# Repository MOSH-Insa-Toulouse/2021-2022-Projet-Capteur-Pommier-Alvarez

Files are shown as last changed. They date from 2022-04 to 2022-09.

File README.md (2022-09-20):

# 2021-2022-Projet-Capteur-Pommier-Alvarez
 
## Description Générale

Dans le cadre de l’unité de formation « Du capteur et banc de test » de l’année scolaire 2021-2022 en quatrième année de Génie Physique à l’INSA Toulouse, nous devions réaliser une jauge de contrainte à base de graphite.

Afin de mener ce projet à bien tout en respectant l’esprit autour de ce capteur (Low tech, low cost et transportable), nous avons utilisé une carte Arduino Uno, un PCB, et différents composants détaillés par la suite.

## Table des matières
* [Livrables](#livrables)
* [Composants](#comp)
* [LTSpice](#spice)
* [PCB Shield](#pcb)
* [Application](#apk)
* [Arduino](#ard)
* [Banc de test](#banc)
* [Datasheet](#data)
* [Améliorations](#ameliorations)

<div id='livrables'/>

## Livrables

Les livrables à l’issu de ce projet sont:
* Un rapport sur le circuit analogique à l'aide du logiciel LTSpice
* Un PCB Shield
* Un code Arduino permettant de collecter et transférer les données du capteur soit
sur un oled soit à un module bluetooth connecté à un Android.
* Une application APK
* Un banc de test
* Une datasheet

<div id='comp'/>

## Composants

Les composants pour la réalisation du circuit analogique sont les suivants :
* Arduino Uno
* LTC1050
* Module Bluetooth HC05
* OLED 128x64
* Encodeur rotatif GT055
* R4 : Capteur papier
* Résistances: 100kOhms (x2), 1kOhms(x2), 10kOhms
* Capacités: 100nF(x3), 1uF

<div id='spice'/>

## LTSpice

Le rapport sur le circuit analogique se trouve dans le dossier [LTSpice](https://github.com/MOSH-Insa-Toulouse/2021-2022-Projet-Capteur-Pommier-Alvarez/tree/main/LTSPICE)

<div id='pcb'/>

## PCB Shield

La première étape dans la création du PCB a été la création du Schematic sur le logiciel KiCAD. Nous devions créer chacun des composants et déterminer à quels pin de l'Arduino étaient connectés chacun ds pins des composants.

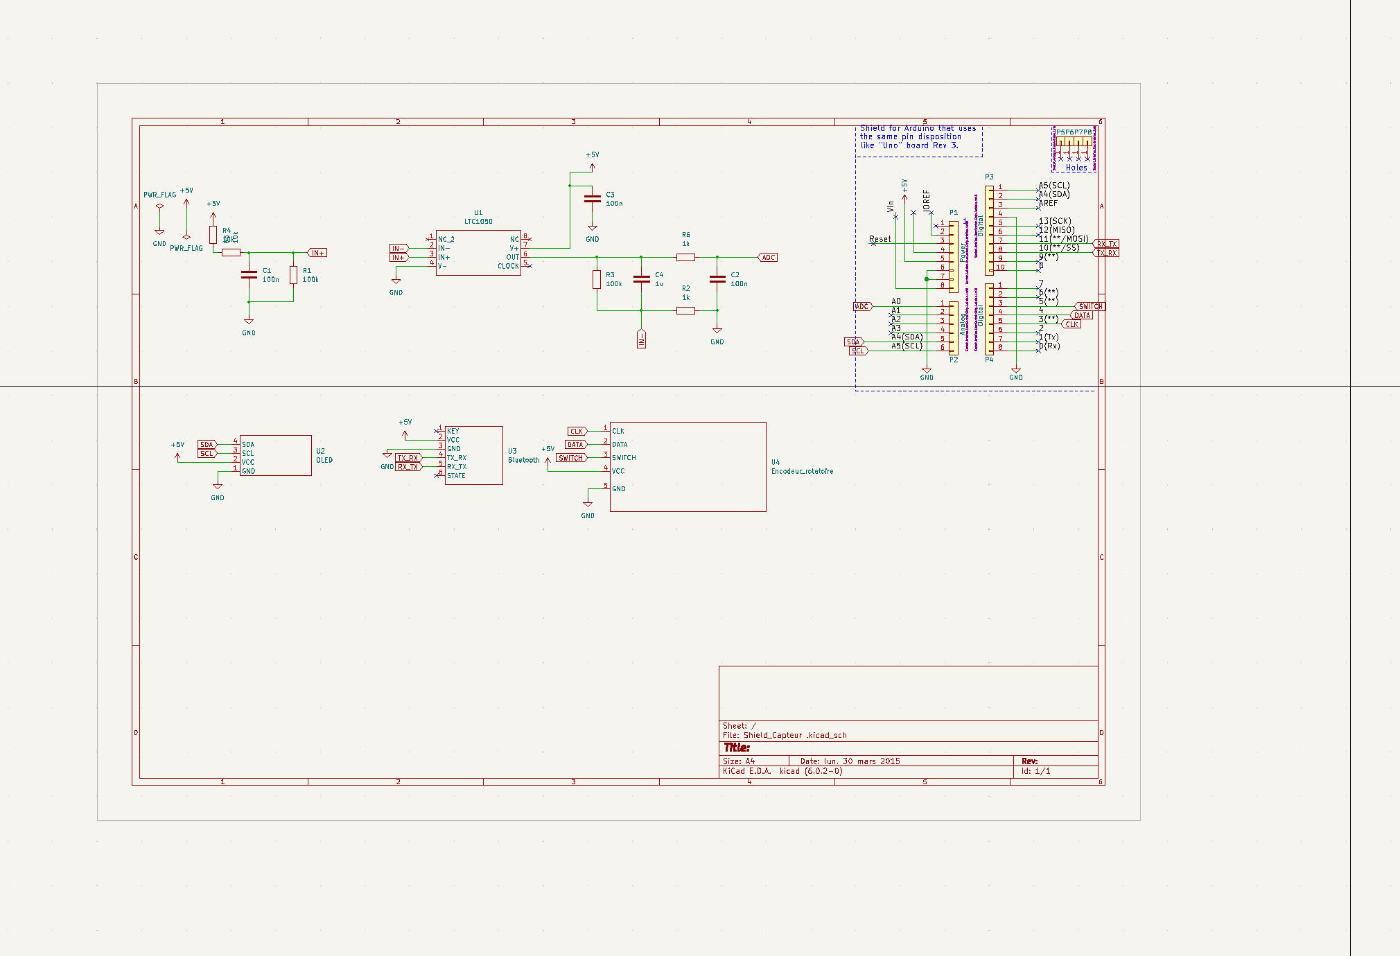
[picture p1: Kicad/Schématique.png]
Shematic


L'étape suivante a été le placement des composants sur le PCB et la connexion entre chaque pin et finalement, la représentation 3D des composants pour s'assurer qu'aucun ne se chevauchaient.

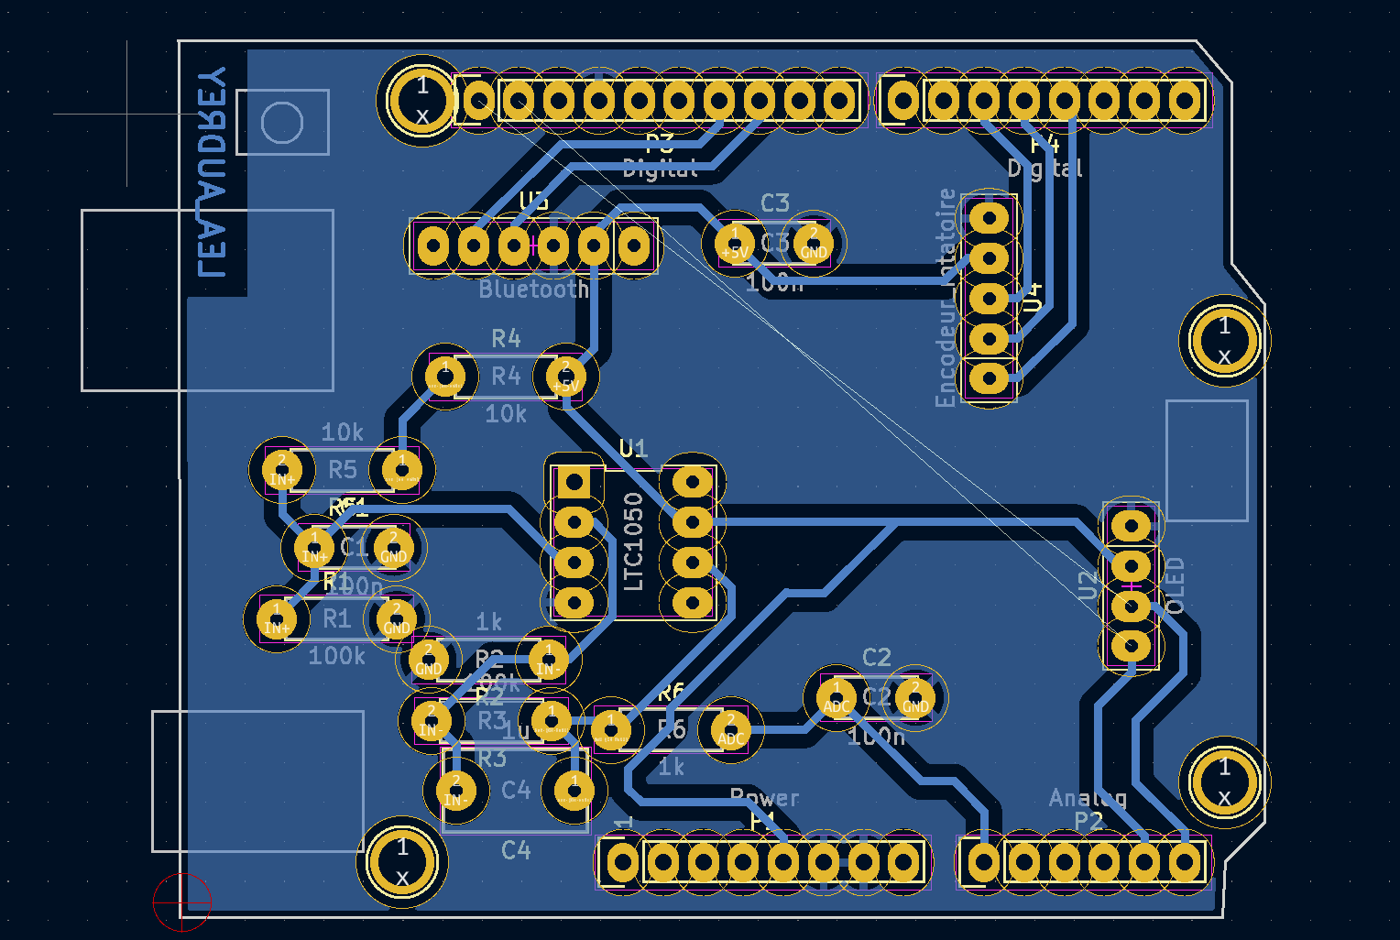
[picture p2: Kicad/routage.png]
routage


Après l'étape de réalisation du PCB avec le logiciel KiCAD est venue l'étape de réalisation physique de celui-ci. C'est avec l'aide de Madame Crouzet que cela a été possible.

Enfin, le PCB a été percé avec des trous de 1mm de diamètre pour les pins de
l'Arduino et 0,8mm de diamètre pour les autres.

Les détails du PCB et du Schematic se trouvent dans le dossier [KiCAD](https://github.com/MOSH-Insa-Toulouse/2021-2022-Projet-Capteur-Pommier-Alvarez/tree/main/Kicad) 

<div id='apk'/>

## Application

Les informations envoyées par le module bluetooth sont récupérées sur une application Android faite grâce au site [MIT App Inventor](https://appinventor.mit.edu/).

Notre application se compose de trois écrans différents. Le premier est une page de garde qui permet d'accéder aux deux autres écrans, soit un écran d'informations générales sur le fonctionnement du capteur soit un écran qui permet la connexion bluetooth et la visualisation des données reçues.
Sur ce dernier la valeur de la résistance est affichée dans une zone texte et tracée au et à mesure sur un graphique.

Voici l'ecran avec le graphique:

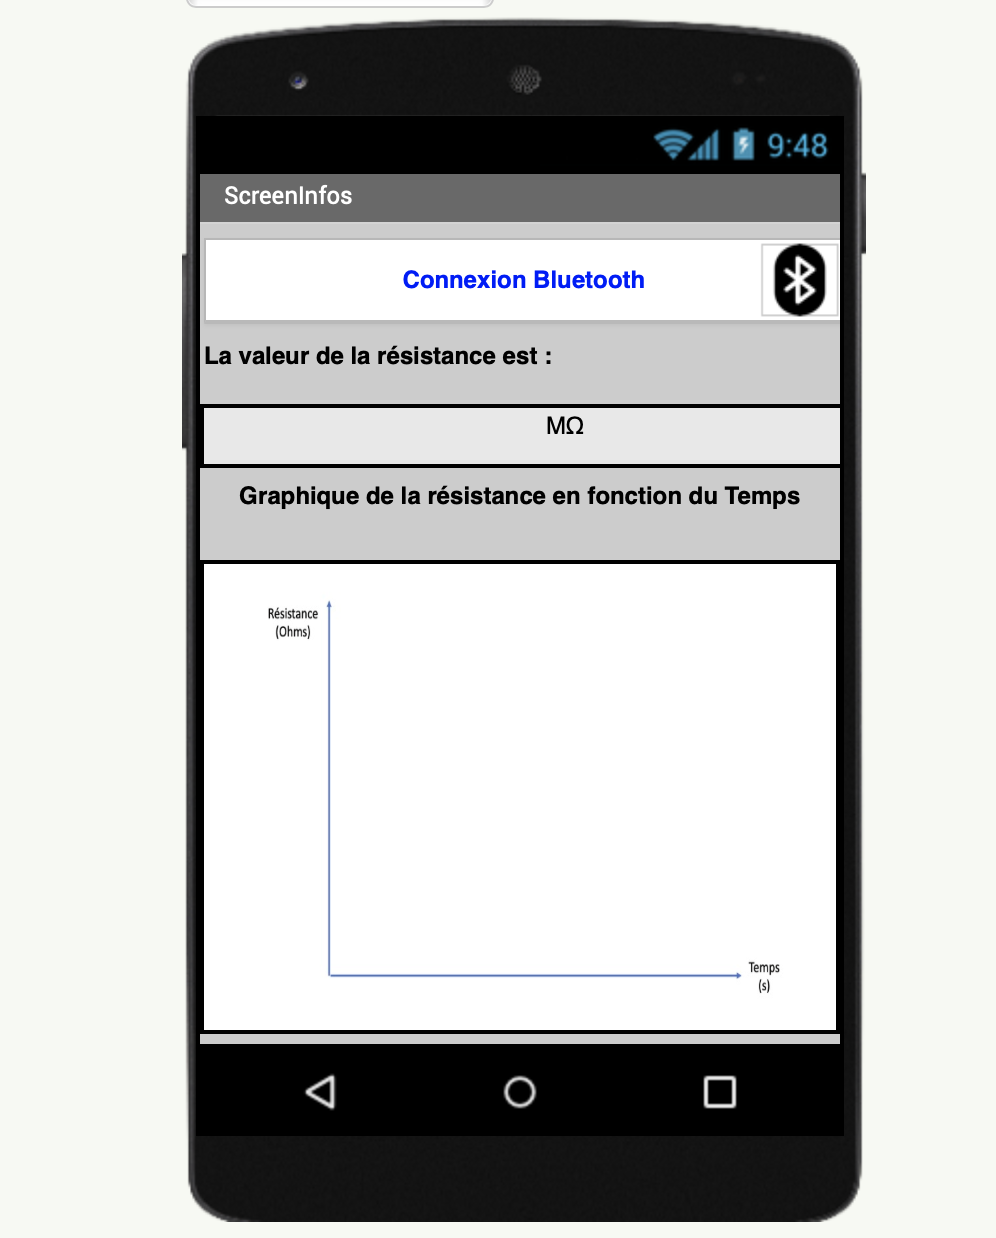
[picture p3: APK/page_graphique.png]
graph


Les photos et le code de l'application se trouvent dans le dossier [APK](https://github.com/MOSH-Insa-Toulouse/2021-2022-Projet-Capteur-Pommier-Alvarez/tree/main/APK)

<div id='ard'/>

## Code Arduino

Afin que tout cela soit possible et fonctionnel nous devions écrire un code Arduino. Celui-ci permet de récupérer les valeurs de la résistances, se connecter au module bluetooth avec un téléphone et les envoyer par la suite. Il permet également de visualiser ces valeur sur un écran OLED constitué de trois menus différents pilotés par l'encodeur rotatif. Ces trois menus sont une page de présentation, une page d'informations et une page avec les valeurs.
Un autre code fut nécéssaire pour pouvoir gérer notre banc de test, celui-ci sera expliqué dans la partie suivante.

Les informations relatives au code se trouvent dans le dossier [Arduino](https://github.com/MOSH-Insa-Toulouse/2021-2022-Projet-Capteur-Pommier-Alvarez/tree/main/Arduino).

<div id='banc'/>

## Banc de test

Afin de pouvoir rédiger notre datasheet mais également de pouvoir connaître la répétabilité de la mesure avec un seul capteur nous avions besoin d'un banc de test. Celui-ci fut réalisé en collaboration avec le groupe de Louis-Maxence Hotton et Thalia Lamy.
Notre banc de test est composé d'un servo-moteur et de pièces recyclées (papier et carton recyclés). Un code Arduino permet de piloter celui-ci et de faire une rotation de 0° à 90°. Afin d'avoir les valeurs en compression et dilatation nous avons retourné le capteur.

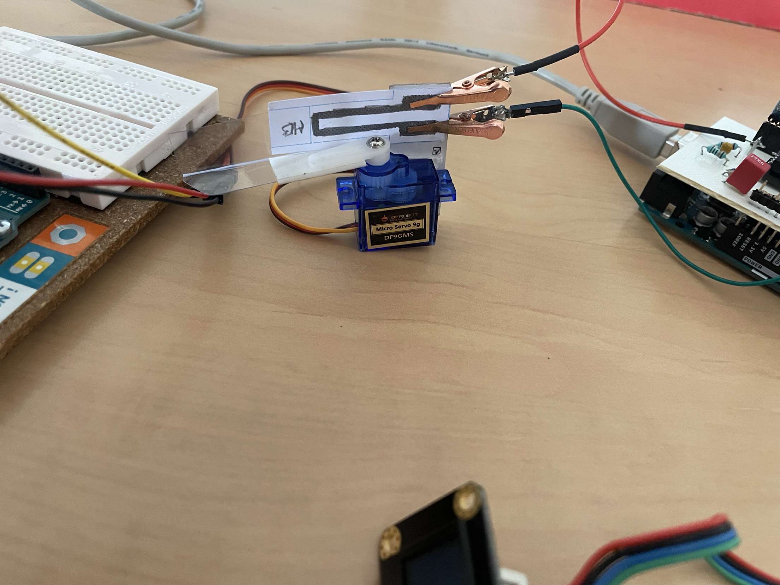
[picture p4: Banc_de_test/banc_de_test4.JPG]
banc de test


Les photos du banc de test sont dans le dossier [banc de test](https://github.com/MOSH-Insa-Toulouse/2021-2022-Projet-Capteur-Pommier-Alvarez/tree/main/Banc_de_test) et le code associé dans le dossier Arduino

<div id='data'/>

## Datasheet

Les données de la datasheet ont été mesurées à l'aide du banc de test décrit ci- dessus. Nous avons fait les mesures avec des crayons HB et 2B. Pour les mesures nous avons fait cinq séries en compression, effectué la moyenne de ces séries et répété l'opération avec la dilatation pour chacun des crayons.
Nous avons testé avec un crayon 6B mais notre programme nous annonçait un overload.

Nous avons estimé la répétabilité de l'expérience à 10 mesures par capteur (papier) soit 5 en compression suivies de 5 en dilatation car après cela les valeurs nous semblaient moins cohérentes avec les premières séries.

La datasheet se trouve dans le dossier [datasheet](https://github.com/MOSH-Insa-Toulouse/2021-2022-Projet-Capteur-Pommier-Alvarez/blob/main/Datasheet%20jauge%20de%20contrainte%20graphite.pdf).

<div id='ameliorations'/>

## Améliorations

L'utilisation du banc de test a nécessité deux cartes Arduino Uno. Il aurait fallu intégrer le servo moteur sur le KiCAD pour pouvoir le mettre sur le PCB et ainsi le faire fonctionner avec une seule carte et un seul programme.

Comme améliorations pour les valeurs de la datasheet, peut être faudrait-il utiliser plusieurs capteurs avec le même crayon (par exemple HB), faire les 10 séries de mesures et faire la moyenne sur toutes les séries des différents capteurs.

On peut également penser pour l'application à l'affichage d'un message pour signaler que la connexion bluetooth s'est effectuée.

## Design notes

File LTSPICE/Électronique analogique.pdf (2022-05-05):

Électronique analogique : simulation sous LTSPICE.

Description générale :

L'objectif de cette partie est de comprendre comment on obtient la résistance de notre capteur à partir du circuit électronique suivant. En effet, l'ordre de grandeur des résistances mesurées sera de 1 Gohms à 500 Kohms. Ce qui signifie que le capteur possède un courant très faible (environ 100 nA). Le montage électrique doit donc comporter un amplificateur opérationnel AOP, dans notre cas il s'agit du LTC1500C (voir datasheet dans le dossier LTSPICE). En effet, le microcontrôleur Arduino Uno ne peut pas mesurer directement de très faible courant C'est pourquoi l’amplificateur opérationnel permettra de convertir ce courant en une tension mesurable par le Arduino Uno.

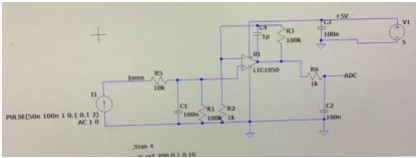
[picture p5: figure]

Schéma électrique du montage

Ce premier schéma permet de réaliser nos mesures pour le capteur graphite. Cependant, si on choisit de prendre le courant du capteur directement en entrée d’amplificateur opérationnel, il est nécessaire que la résistance d'entrée soit très grande pour amplifier le signal et que la tension d'alimentation soit négative. De plus, sous LTSpice, il est possible de voir le courant d'entrée de l’amplificateur opérationnel qui est de 125 pA. En effet, le courant d'entrée doit être très petit devant le courant de notre capteur (100 nA) afin que le courant du capteur traverse la résistance R1 et pas l'entrée de l'amplificateur opérationnel. De plus, si le courant de polarisation et trop grand, cela impactera la tension de sortie et donc faussera le calcul de la résistance.

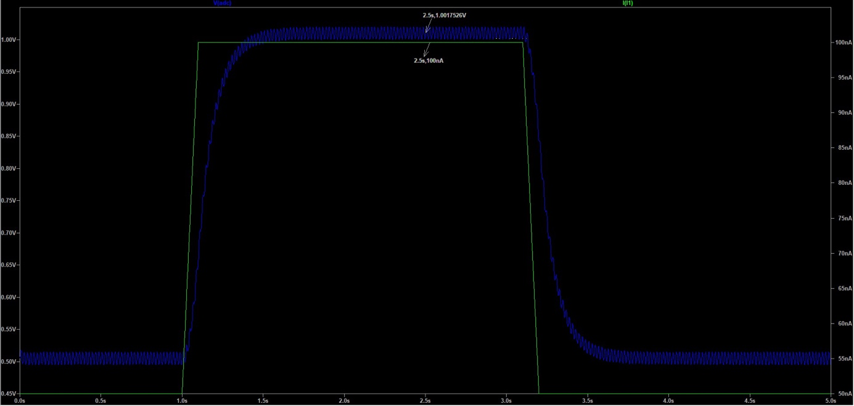
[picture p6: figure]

Mise en évidence : 100nA et 1V

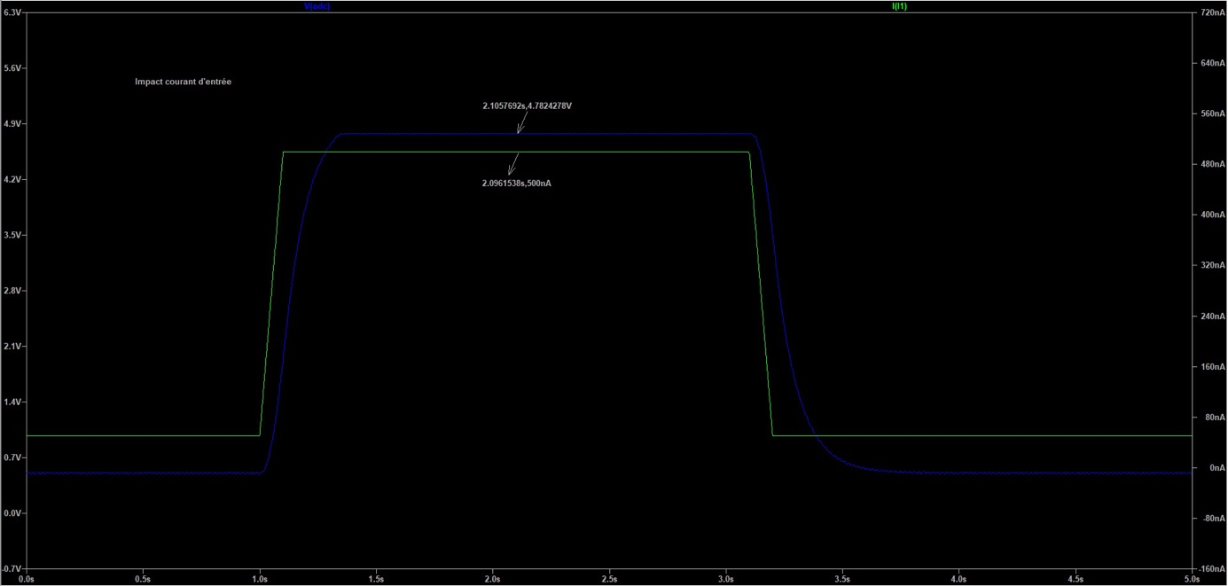
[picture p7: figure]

Mise en évidence : 500nA et 5V

Il est facile de remarquer que si la tension du capteur est de 100 nA, la tension de sortie ADC peut aller jusqu'à un Volt. En revanche, si la tension du capteur est de 500 nA, la tension de sortie ADC peut aller jusqu'à 5 volts. Afin de minimiser ce problème, il faudrait que la résistance R2 soit un potentiel digital afin de réguler celle-ci et de permettre de ne jamais saturer.

Il est intéressant de savoir si elle exerce une influence sur la tension de sortie mesurée. En effet l'offset est une erreur constante aux entrées de l’amplificateur différentiel dû à un état non compensé sur l'étage d'entrée de l'amplificateur. On veut que l’offset soit négligeable devant la tension mesurée. Or d'après la datasheet du LTC1500C, il y a un offset de 05 microvolts (valeurs typiques) et le gain maximal de l’AOP et de 160 dB. Ce qui correspond à un offset de sortie d'environ 50 volts. Cependant la tension mesurée sur R1 est de 10 millivolts, ce qui correspond à une tension en sortie de l’AOP d'environ un giga Volt (10 mV * Gain (le calcul n’est pas exactement cela car il faut prendre en compte les différents filtres…)). On a donc un offset bien plus faible que la tension mesurée, il est donc acceptable d'avoir cet offset.

Les filtres intégrés :

Considérons à présent les différents filtres mis sur ce circuit. En effet, on peut identifier trois filtres passe-bas sur ce circuit analogique.

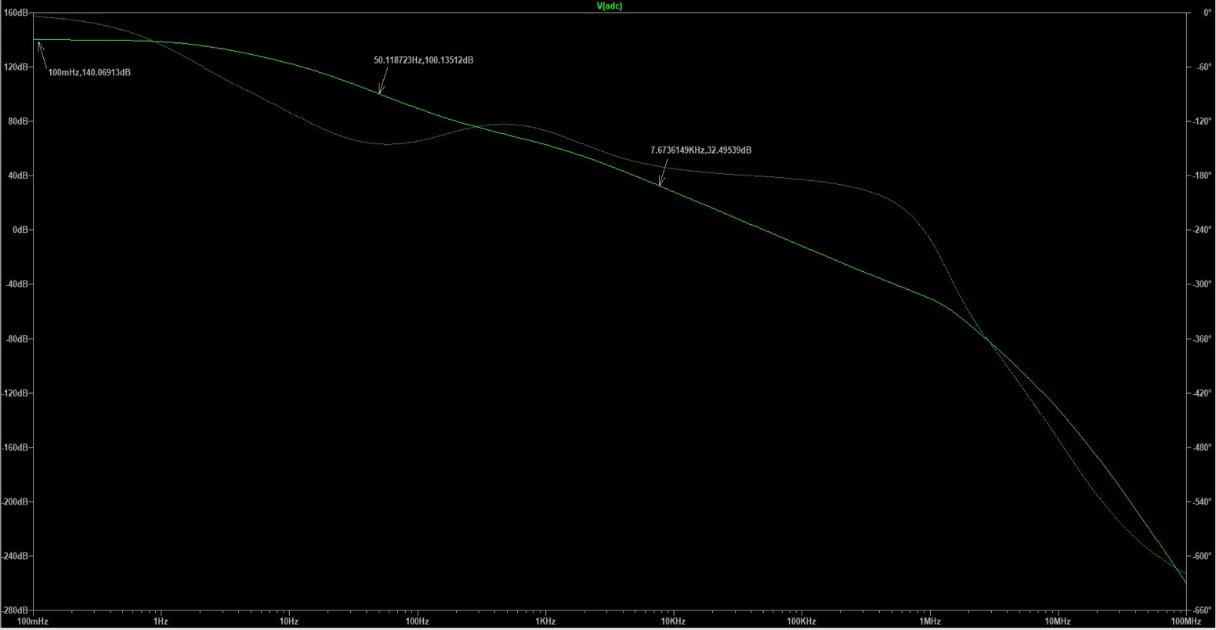
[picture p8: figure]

Trois filtres présents

Le premier filtre identifiable est celui composé de la résistance R1 et de la capacité C1. Celui-ci est un filtre passe-bas permettant de filtrer le bruit en courant et d'éviter toute perturbation liée aux perturbations de type radiofréquence.

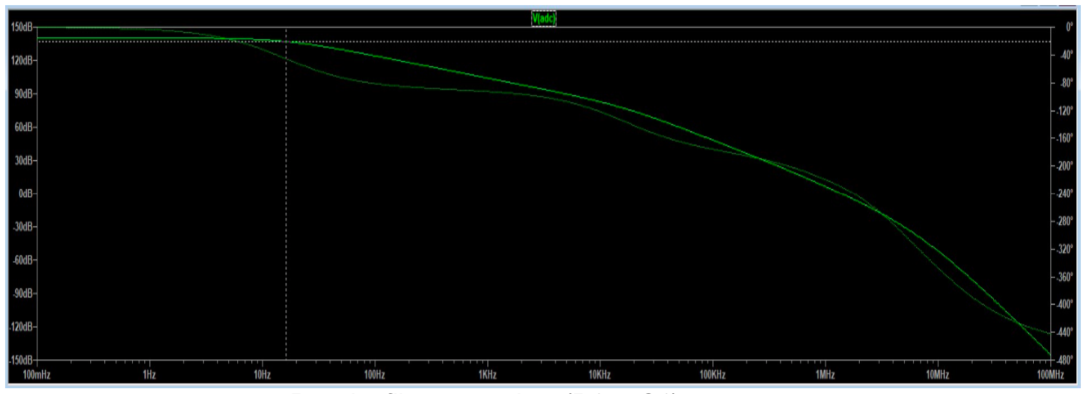
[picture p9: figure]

Premier filtre passe-bas (R1 et C1)

À partir de cette photo, on peut retrouver la fréquence à – 3dB qui est de 15, 5 hertz. Alors que la fréquence de coupure théorique est de : f1=1/ (2*3,14* R1*C1) = 15,9Hz.

Le deuxième filtre identifiable est celui composé de la résistance R3 et de la capacité C4. Ce filtre permet entre autres de couper le 50 hertz. C'est à dire toutes les alimentations autour peuvent avoir une composante parasite qui perturbent le signal.

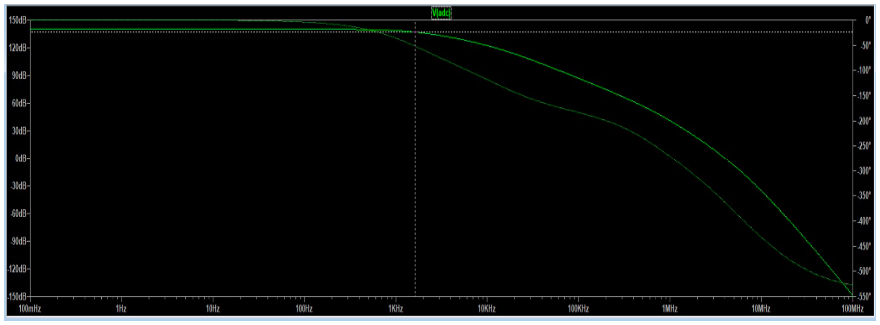
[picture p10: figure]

Second filtre (R3 et C4)

À partir de cette photo, on peut retrouver la fréquence de coupure à - 3 décibels qui est de 1,60 hertz. Théoriquement, f2=1/ (2*3,14* R3*C4) = 1,59Hz.

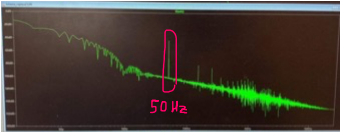
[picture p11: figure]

Pic à 50Hz

Pour simuler le problème des alimentations à 50 hertz, on a ajouté sur le circuit un générateur de tension sinusoïdale de fréquence 50 hertz en série avec la capacité de couplage. On met également la capacité C4 à 0 afin d’observer le pic à 50 hertz. Sur cette photo (FFT de la tension ADC), le pic à 50 hertz est largement visible.

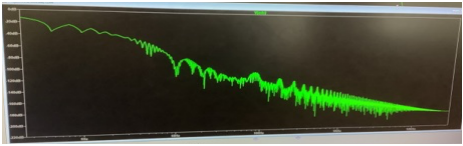
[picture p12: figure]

Atténuation pic à 50Hz

Ensuite, on remet la capacité C4 à 1uF, puis on observe que le pic à 50 Hertz est largement atténué. On peut donc mesurer cette atténuation en se plaçant à 50 hertz et en relevant le gain. (100-140 dB) On a donc une atténuation de -40 dB.

Quant au dernier filtre, composé de la résistance R6 et la capacité C2, celui-ci sert à atténuer toutes fréquences de bruit qui perturberait le traitement du signal. Il s'agit donc des fréquences hautes. En effet, la fréquence de Nyquist est la plus grande fréquence utilisable sans perte de qualité. Pour un Arduino Uno, il s'agit de la fréquence égale à 15,4 KHz (200kHz/13(voir datasheet Arduino)). Sachant que pour obtenir un signal sans perte de qualité, il faut respecter le critère de Shannon qui énonce que la fréquence des échantillonnages doit être supérieure ou égale à la fréquence du signal fois 2. Il est donc évident de comprendre que la fréquence de Nyquist est 7,5 kilohertz.

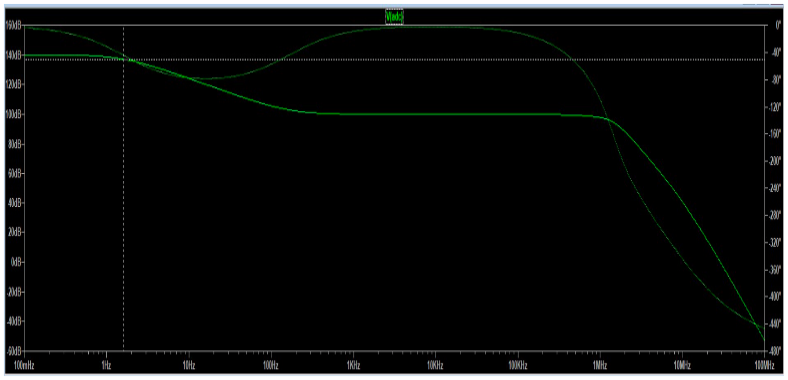
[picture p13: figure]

Troisième filtre (R6 et C2)

À partir de cette photo, on peut retrouver la fréquence de coupure égale à 1,6 kilohertz. Théoriquement nous obtenons 1591 hertz. Ainsi on préserve la fréquence du signal.

On peut mesurer l'atténuation concernant la fréquence de Nyquist et on obtient -107 décibels (33-140 dB). Cette fréquence est également appelée fréquence limite de repliement car elle permet d'éviter le repliement de spectre.

À partir de ce schéma électrique, on peut retrouver la résistance du capteur :

RS= (1+

R3 / RCAL) ×R1×(

VCC/ VADC )−R1−R5

Raisonnement avec notre capteur :

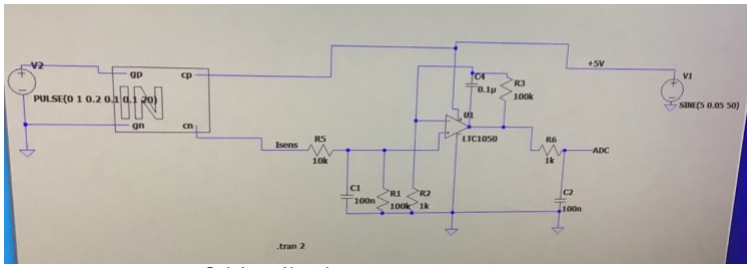
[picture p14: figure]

Schéma électrique avec notre capteur

À partir de ce schéma, on peut remarquer que nous avons remplacé la source de courant par notre capteur. Celui-ci est alimenté en 5 volts dont la conductance varie de 10nS à 20nS en 0.2s.

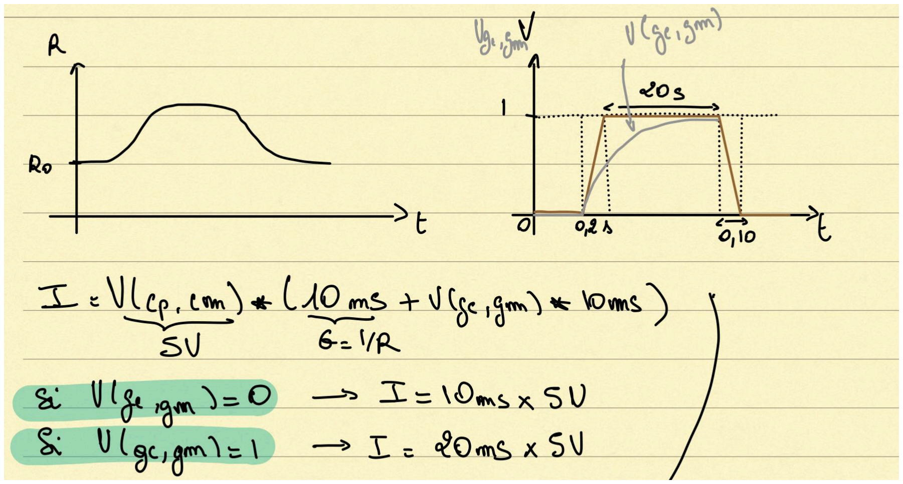
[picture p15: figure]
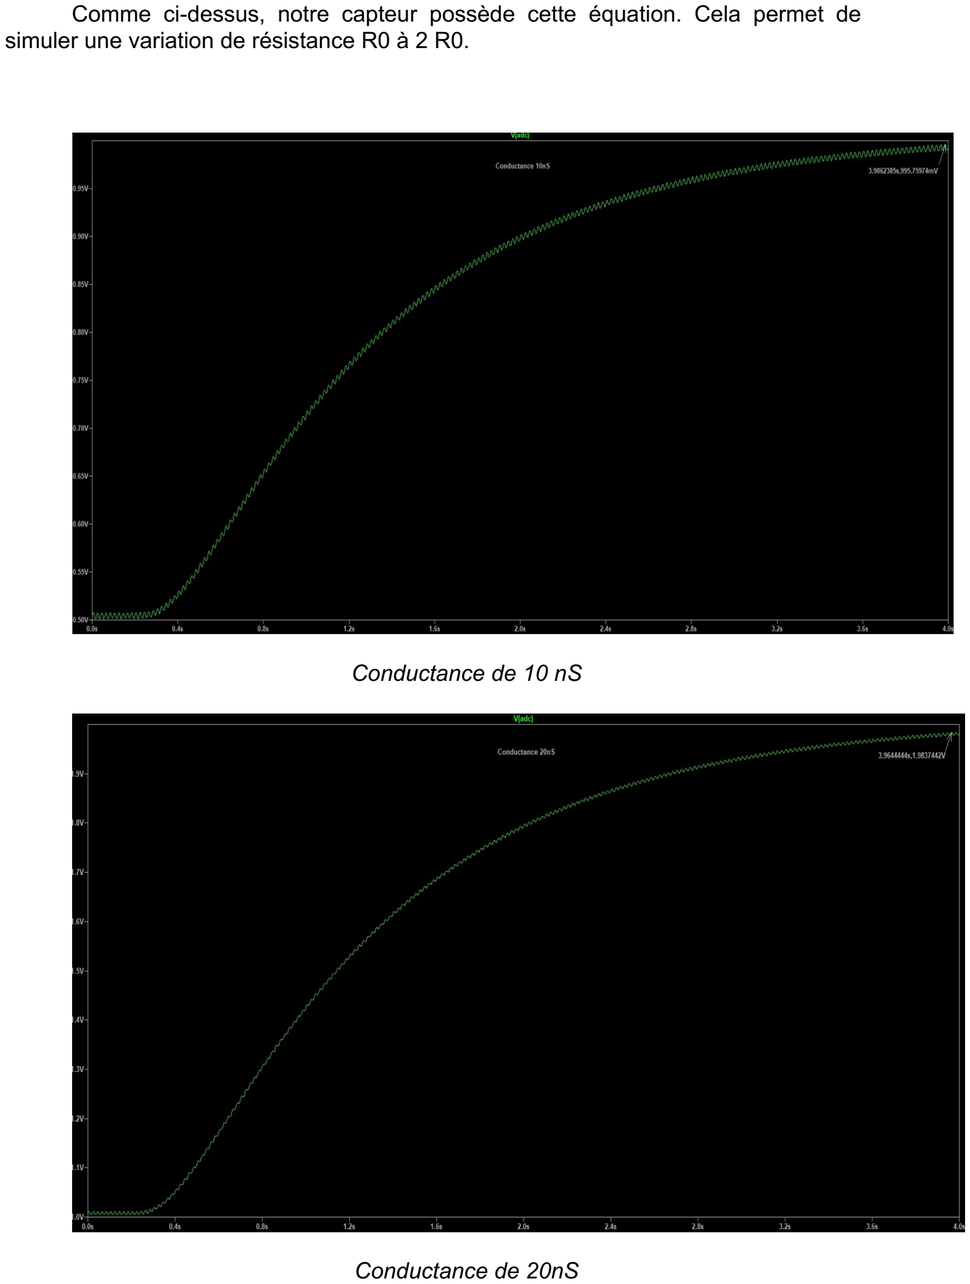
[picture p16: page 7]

Comme ci-dessus, notre capteur possède cette équation. Cela permet de simuler une variation de résistance R0 à 2 R0.

Conductance de 10 nS

Conductance de 20nS

À partir de cela en faisant une analyse transitoire, nous pouvons remarquer qu’on voit les « vaguelettes » du 50 hertz mais le rapport signal sur bruit reste correct. Également, lorsqu'on augmente la conductance le rapport signal sur bruit diminue. Donc le bruit devient gênant. En effet pour une conductance de 10nS, le signal peut atteindre jusqu'à un Volt alors que pour la conductance de 20ns, nous obtiendrons au maximal un signal à 4V. Ce qui commence à être problématique car l’Arduino ne peut considérer des valeurs de tensions qu’entre 1V et 5V. En revanche, les « vaguelettes » du 50 hertz diminuent.

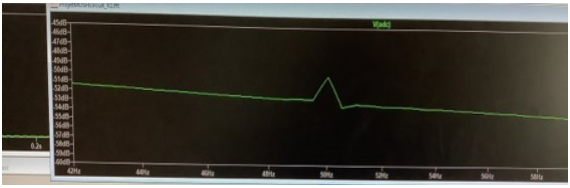
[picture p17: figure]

Pic à 50Hz de 3dB (53dB-50dB)

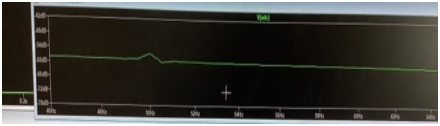
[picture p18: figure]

Pic à 50Hz (60dB-54dB)

Si nous faisons une transformée de Fourier de ces signaux, nous remarquons que le pic à 50 hertz pour une conductance de 10 nS est de 6 décibels. Alors que le pic à 50 hertz pour une conductance de 20 nS est de 3 dB.

Enfin, même si nous n'avons pas réalisé un capteur de gaz à l’AIME, nous avons tout de même simulé son comportement en alimentant le capteur à 20V. et nous avons regardé pour une conductance de 10 nS et 20nS.

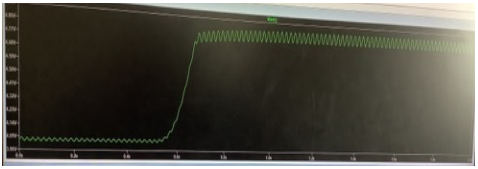
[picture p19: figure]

Conductance 20nS pour une alimentation à 20V

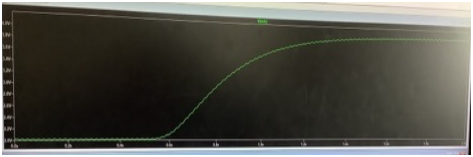
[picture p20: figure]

Conductance de 10nS pour une alimentation à 20V

Nous pouvons remarquer que pour une conductance de 10 nS, le signal reçu n’a pas beaucoup de bruit dû au 50Hz en revanche, la tension atteint 4V. Et pour la conductance de 20 nS, le bruit devient très gênant (voir photo) et la tension reçue est de 4,95V. Ce qui correspond quasiment à la limite de l’Arduino qui va saturer.

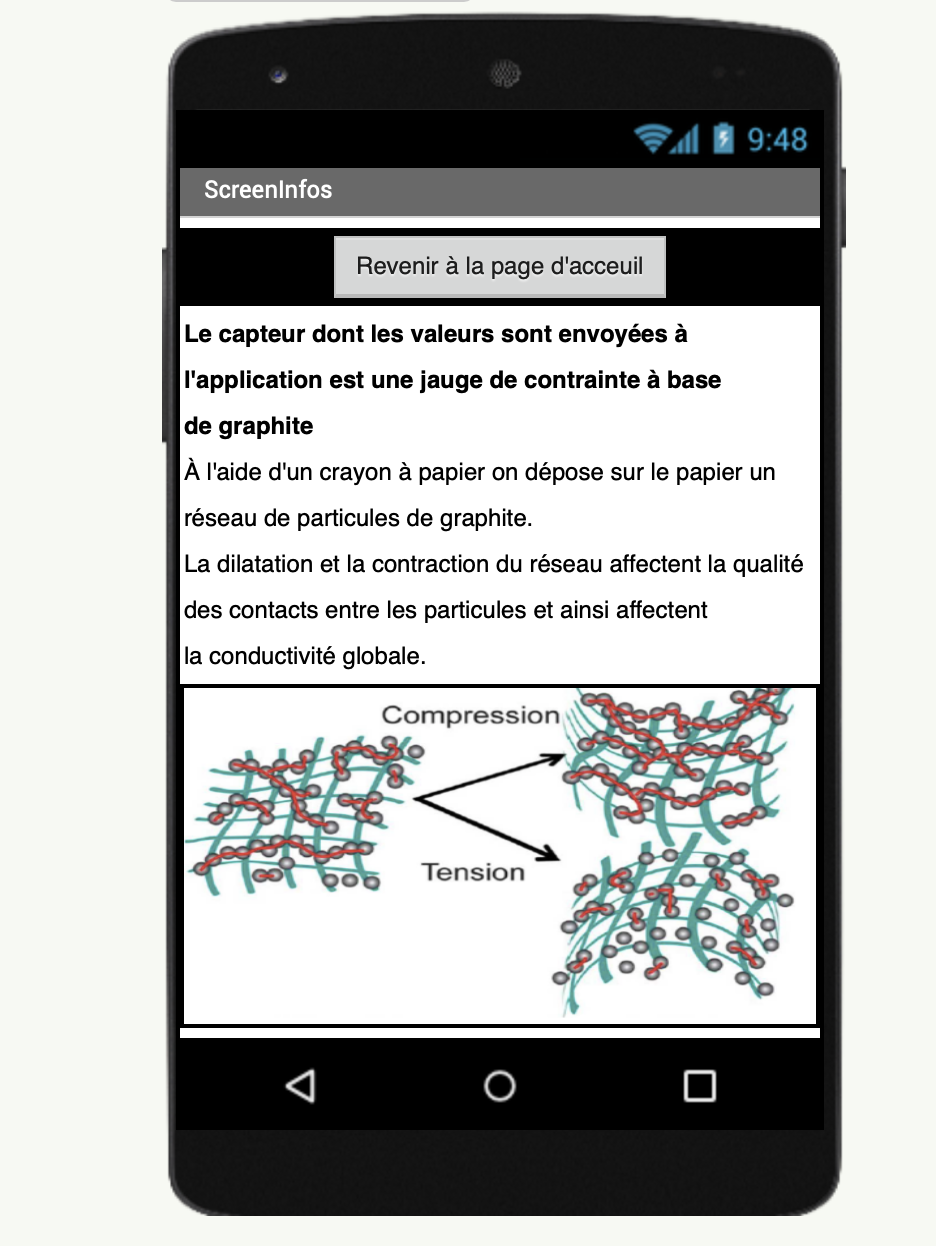
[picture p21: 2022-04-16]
APK/Page_information.png

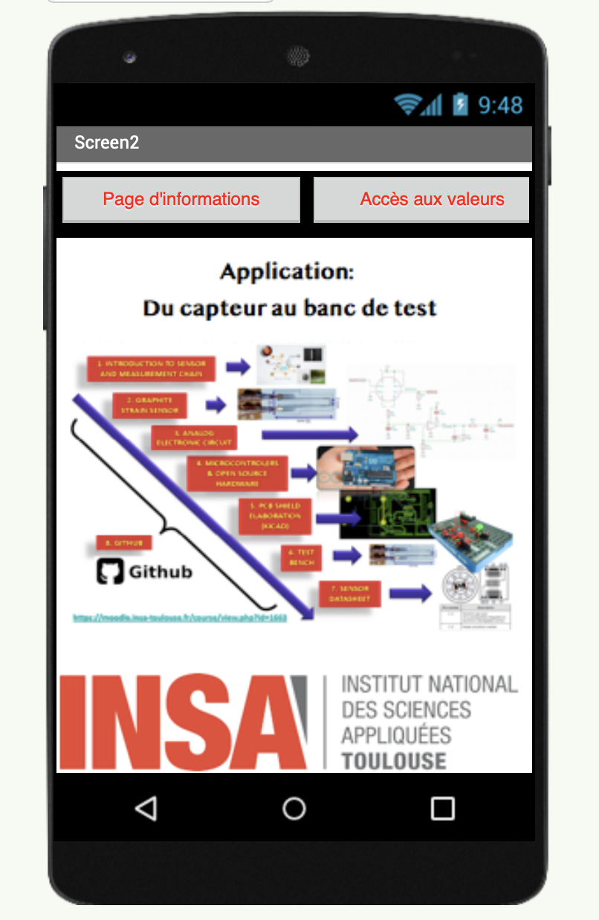
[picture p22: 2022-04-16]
APK/page_acceuil.png

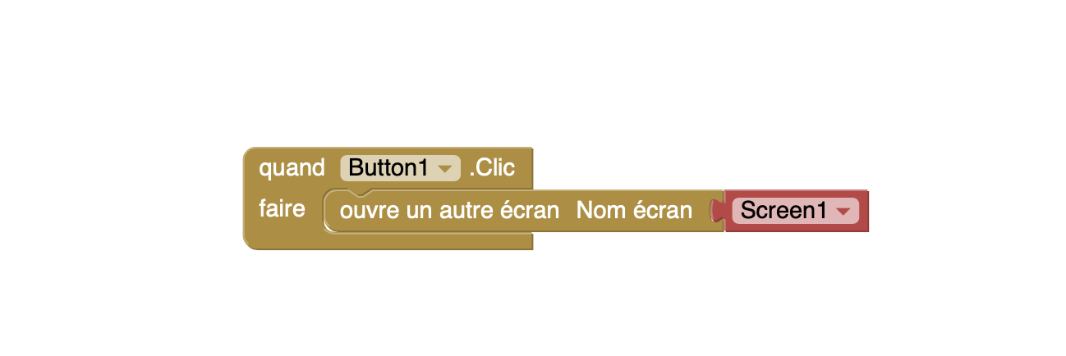
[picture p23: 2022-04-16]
APK/code_information.png

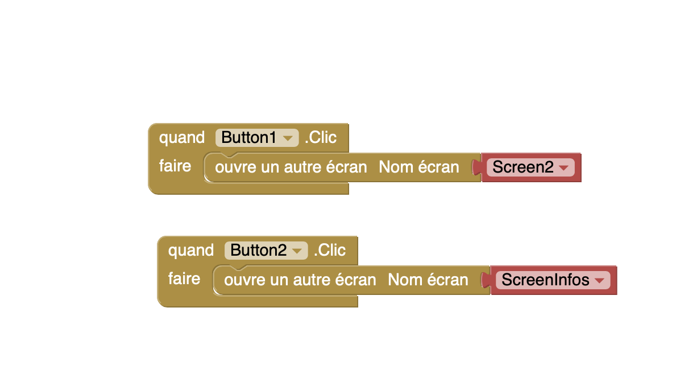
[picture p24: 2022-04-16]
APK/code_ecran_acceuil.png

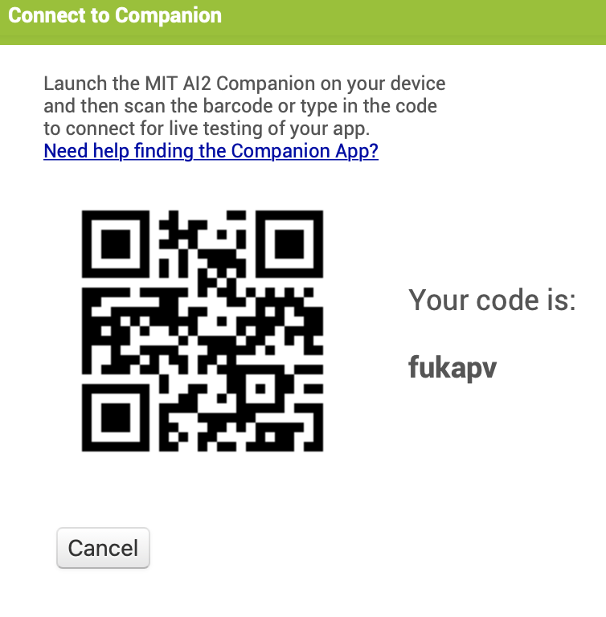
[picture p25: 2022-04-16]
APK/connexion.png

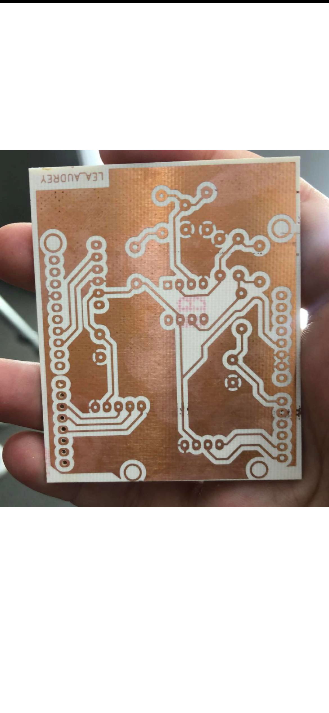
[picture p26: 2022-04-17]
Kicad/PCB_termine.png

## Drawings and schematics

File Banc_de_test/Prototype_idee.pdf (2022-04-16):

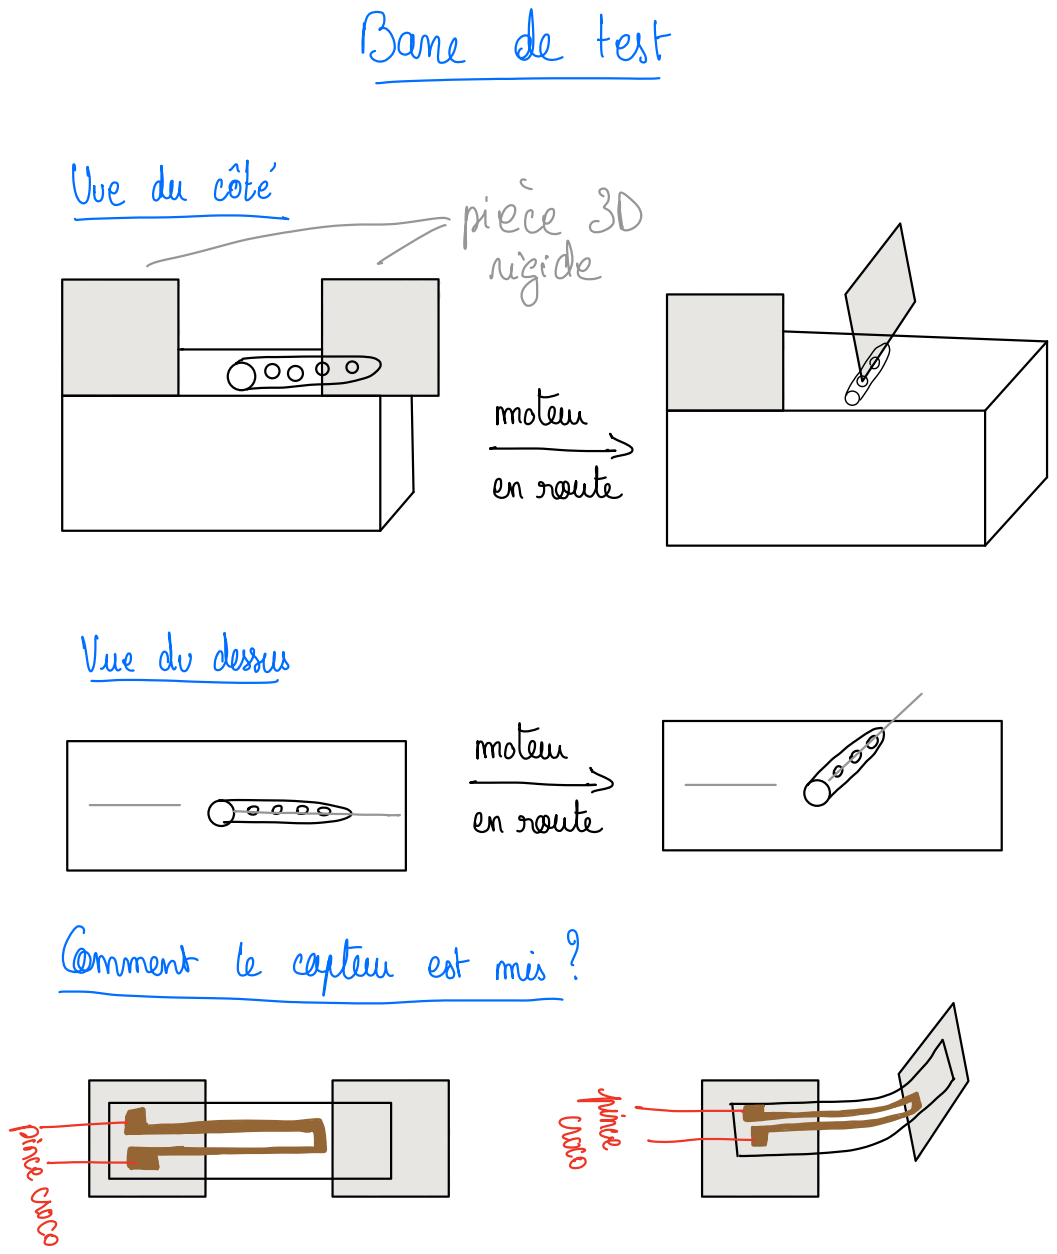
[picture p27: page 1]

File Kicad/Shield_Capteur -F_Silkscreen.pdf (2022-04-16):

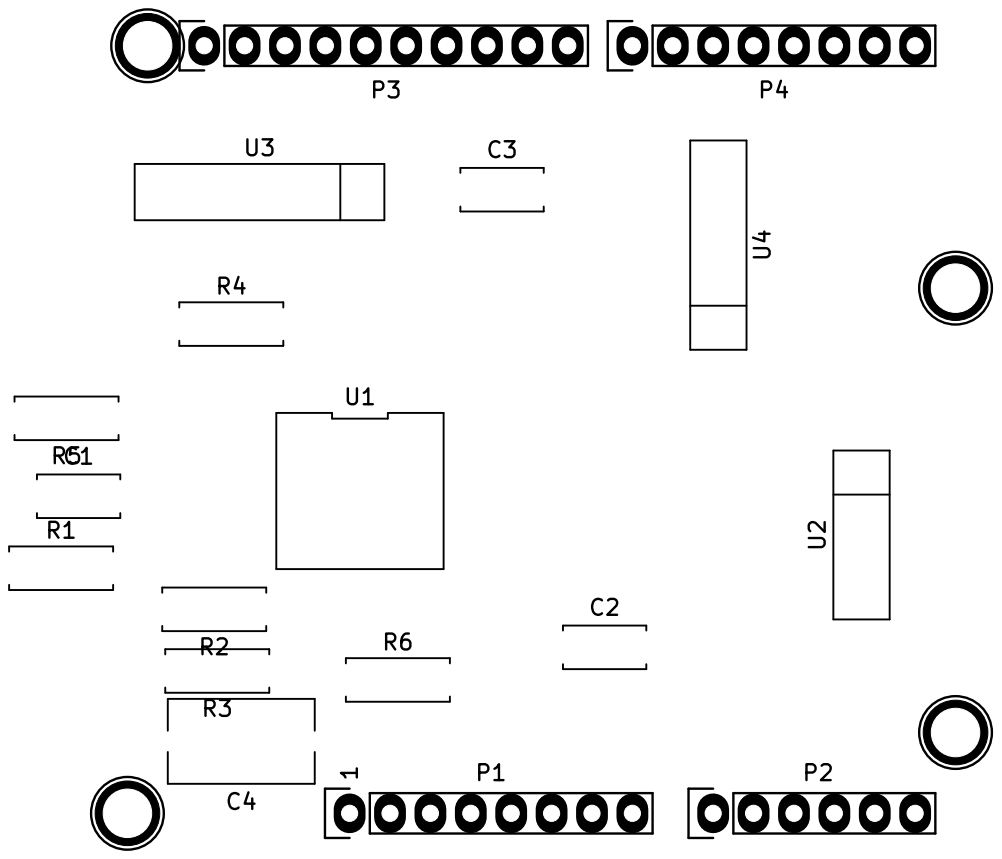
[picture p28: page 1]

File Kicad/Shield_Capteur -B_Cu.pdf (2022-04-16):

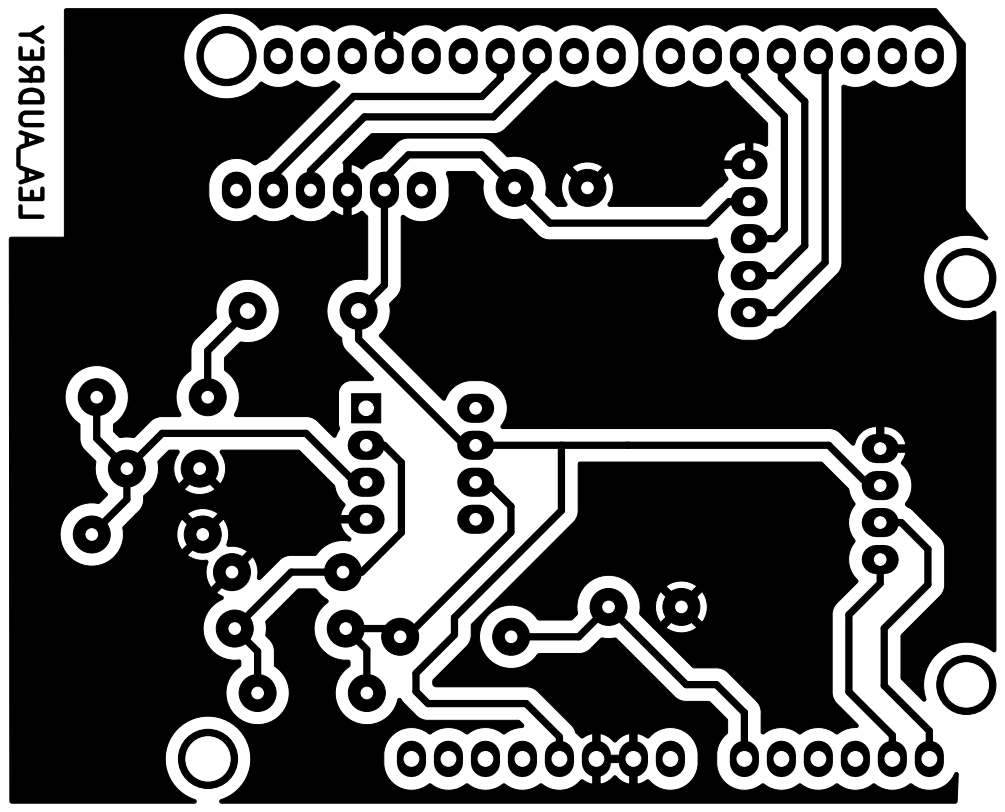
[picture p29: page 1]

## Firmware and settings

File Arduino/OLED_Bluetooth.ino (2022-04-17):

//////////Définition des bibliotheques//////////
#include <SoftwareSerial.h>
#include <SPI.h>
#include <Wire.h>
#include <Adafruit_GFX.h>
#include <Adafruit_SSD1306.h>

///////// Definition des pins///////
/***encodeur***/
#define encoder0pinA 3 // CLK
#define encoder0pinB 4 // DATA
#define Switch 5 // switch


/***oled***/
#define SCREEN_WIDTH 128
#define SCREEN_HEIGHT 32
#define OLED_RESET -1
#define SCREEN_ADDRESS 0x3C ///< See datasheet for Address; 0x3D for 128x64, 0x3C for 128x32
Adafruit_SSD1306 display(SCREEN_WIDTH, SCREEN_HEIGHT, &Wire, OLED_RESET);

/*** Bluetooth***/ 
#define rxpin 11
#define txpin 10
#define baudrate 9600
SoftwareSerial mySerial(rxpin,txpin);
#define Periode 50 
#define analog_port 0

///// Definition des variables/////
/**Bluetooth***/
unsigned long temps_ref;

/***oled et debouncing***/
const int ledPin=13;
int ledState=HIGH;
int buttonState;
int lastButtonState=HIGH;
int compteur_filtre;
int compteur_non_filtre;

long lastDebounceTime=0;
long debounceDelay=50;

Adafruit_SSD1306 ecranOLED(SCREEN_WIDTH, SCREEN_HEIGHT, &Wire, OLED_RESET);

byte dir = 0;

int compteurSwitch=0;

/***encoder***/
volatile unsigned int encoder0pos=0;
int Switchstate=0;


//////// Programme principal////////


void setup() {

//Bluetooth
  pinMode (rxpin, INPUT);
  pinMode (txpin, OUTPUT);
  temps_ref=millis();
  mySerial.begin(baudrate);
  Serial.begin(baudrate);

  
// OLED
  ecranOLED.begin(SSD1306_SWITCHCAPVCC, SCREEN_ADDRESS);
  pinMode (encoder0pinA,INPUT);
  digitalWrite(encoder0pinA,HIGH);
  pinMode (encoder0pinB,INPUT);
  digitalWrite(encoder0pinB,HIGH);
  pinMode(Switch, INPUT);
  
  attachInterrupt(0,doEncoder,RISING);

  

  if(!ecranOLED.begin(SSD1306_SWITCHCAPVCC,0x3C)){
    while(1);
  }
  
  ecranOLED.setTextColor(SSD1306_WHITE);
  ecranOLED.clearDisplay();
  ecranOLED.setTextSize(1);

//affichage OLED
  ecranOLED.setCursor(0,0);
  ecranOLED.print("Projet Capteur");
  ecranOLED.print(" Pommier et Alvarez");
  ecranOLED.display();
  delay(2000);
  ecranOLED.clearDisplay();
  
//Debouncing
  Serial.begin(9600);
  pinMode(Switch,INPUT);
  pinMode(ledPin,OUTPUT);
 }

void loop() {
  
  ecranOLED.clearDisplay();
  Serial.print("Position:");
  Serial.println(encoder0pos, DEC);

  double voltage;
  double resistance;
  voltage=analogRead(A0); // recupere la valeur en sortie 
  resistance=(1+100000/1000)*100000*(1023/voltage)-100000-10000; // calcul de la resistance à partir de la tension (voir LTSPICE)
  
//Bluetooth
  if (abs(millis()-temps_ref) > Periode)
  {
//    byte V = map(voltage,0,1023,0,255);
//    mySerial.write(V);
      mySerial.print(resistance);
      Serial.println(resistance);
      
  }
  temps_ref=millis();
  Serial.println("la valeur de ADC "+ String(voltage*5/1023)+ " Volts");
  delay(500);
  
  // etat bouton encodeur
  Switchstate=digitalRead(Switch);

    if(compteur_filtre == 0){
      ecranOLED.setCursor(0,0);
      ecranOLED.print("Projet Capteur");
      ecranOLED.setCursor(0,15 );
      ecranOLED.print("Appuyez sur encodeur");
      ecranOLED.setCursor(0,25 );
      ecranOLED.print("pour changer de menu");
      ecranOLED.display();
      
    }

   
    if(compteur_filtre == 1){
      ecranOLED.setCursor(0,0);
      ecranOLED.clearDisplay();
      ecranOLED.print("Page resistance");
      ecranOLED.setCursor(10,15);
      ecranOLED.println(resistance);
      ecranOLED.setCursor(10,25);
      ecranOLED.print("ohms");
      ecranOLED.display();
      

    }

     if(compteur_filtre == 2){
      ecranOLED.setCursor(10,0);
      ecranOLED.clearDisplay();
      ecranOLED.print("Voici un capteur");
      ecranOLED.setCursor(10,7);
      ecranOLED.print(" a base de graphite");
      ecranOLED.setCursor(10,17);
      ecranOLED.print(" dont le mesurande");
      ecranOLED.setCursor(10,25);
      ecranOLED.print("est une resistance");
      ecranOLED.display();
      

    }

     if(compteur_filtre == 3){
      compteur_filtre=0;

    }
    
// Debouncing

    int reading=digitalRead(Switch);
    if(reading!=lastButtonState){
      lastDebounceTime=millis();
      if(reading==0){
        compteur_filtre=compteur_filtre+1;
      }
      buttonState=reading;
    }
    digitalWrite(ledPin,buttonState);
    lastButtonState=reading;
    Serial.print("Compteurs:");
    Serial.print(compteur_non_filtre);
    Serial.print(",");
    Serial.println(compteur_filtre);
}


/////// Definir les fonctions///////

void doEncoder() {
  if (digitalRead(encoder0pinA) == HIGH) {
    if (digitalRead(encoder0pinB) == LOW && encoder0pos > 0) {
      encoder0pos = encoder0pos - 1;
      dir = 0;
    }
    else {
      encoder0pos = encoder0pos + 1;
      dir = 1;
    }
  }
  else
  {
    if (digitalRead(encoder0pinB) == LOW ) {
      encoder0pos = encoder0pos + 1;
      dir = 1;
    }
    else {
      if (encoder0pos > 0) {
        encoder0pos = encoder0pos - 1;
        dir = 0;
      }
    }
  }
}

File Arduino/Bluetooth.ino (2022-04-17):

/////////Définition des bibliotheques//////////
#include <SoftwareSerial.h>

///////// Definition des pins///////

#define rxPin 11
#define txPin 10
#define baudrate 9600
SoftwareSerial mySerial(rxPin,txPin);

//////// Programme principal////////

void setup() {
  pinMode(rxPin,INPUT);
  pinMode(txPin,OUTPUT);

  mySerial.begin(9600);
  Serial.begin(baudrate);
  Serial.println("demarrage"); /* cette ligne permet de savoir quand les mesures commencent, pratiques pour le banc de test*/ 
}

void loop() {
  int i=2;
  double voltage;
  double resistance;
  voltage=analogRead(A0); /* permet de réccupérer la tension*/ 
  //Serial.println("la valeur de ADC "+ String(voltage*5/1023)+ " Volts"); /* permet de convertir ce qu'on reccupère en volt*/ 
  resistance=(1+100000/1000)*100000*(1023/voltage)-100000-10000; /* calcul de la resistance a partir de la tension */ 
  resistance=resistance/1000000;
  
  
  mySerial.print(resistance);
  Serial.println(resistance);
  delay(500);
  
  

}

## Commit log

2022-04-16 Create Shield_Capteur -B_Cu.gbr
    [Shield_Capteur -B_Cu.gbr]
2022-04-16 Create Shield_Capteur -F_Silkscreen.gbr
    [Shield_Capteur -F_Silkscreen.gbr]
2022-04-16 Create Shield_Capteur -job.gbrjob
    [Shield_Capteur -job.gbrjob]
2022-04-16 Create Datasheet jauge de contrainte graphite.pdf
2022-04-17 Create Capture d’écran 2022-04-15 à 18.48.23.png
2022-05-05 Update Datasheet jauge de contrainte graphite.pdf
